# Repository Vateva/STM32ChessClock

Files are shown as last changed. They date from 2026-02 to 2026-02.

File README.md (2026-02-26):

# STM32ChessClock
Two-player chess clock built on an STM32F103C8 (Blue Pill) with dual SH1106 OLED displays, rotary encoders, and 6 time control modes.

Each player has their own display, rotary encoder, and dedicated buttons. The menu system allows fully independent configuration of starting time, time control mode, and bonus time per player -- making it easy to play odds games (e.g. 10 min vs 5 min, or different time control modes for each player).

## Table of Contents
- [Hardware Components](#hardware-components)
- [Assembly](#assembly)
- [Pinout Configuration](#pinout-configuration)
- [Key Features](#key-features)
  - [Game State Machine](#game-state-machine)
  - [6 Time Control Modes](#6-time-control-modes)
  - [Independent Player Menus](#independent-player-menus)
  - [Time Editor](#time-editor)
  - [Input System](#input-system)
  - [Buzzer](#buzzer)
  - [Boot Animation](#boot-animation)
  - [Display](#display)
- [Technical Specifications](#technical-specifications)
  - [Software Architecture](#software-architecture)
  - [Coordinator Pattern](#coordinator-pattern)
- [Build Environment](#build-environment)
- [Configuration](#configuration)
- [Usage](#usage)
- [License](#license)

## Hardware Components
- STM32F103C8 (Blue Pill) running at 8 MHz HSI
- 2x 1.3" OLED + EC11 rotary encoder modules (SH1106 128x64 I2C display, rotary encoder, and 2 tactile buttons per module)
- 2x Tactile buttons (tap per player)
- 1S lithium battery voltage meter module
- Piezo buzzer (8500 Hz)
  
chessclock components

## Assembly

### Prototyping

chessclcok breadboard

### Solder the components together

chesscolockl soldering

### Design and print the casing
<!-- TODO: Add casing photo -->

The `chessclock-CAD/` folder includes all the STL files needed to print the casing and a gift box, as well as the Blender source files if you want to modify the designs.

### Finished product

finished chessclokc

https://github.com/user-attachments/assets/36cff737-d65f-408a-ad59-bc486b68077b

https://github.com/user-attachments/assets/38348769-685e-4487-b6a5-1dc7a97dfc77

## Pinout Configuration

### Player 1
```cpp
// Display (I2C1)
SCL = PB6
SDA = PB7

// Rotary Encoder
CH_A = PA0
CH_B = PA1

// Buttons
Encoder Push = PA2
Menu         = PA3
Back         = PA4
Tap          = PA15
```

### Player 2
```cpp
// Display (I2C2)
SCL = PB10
SDA = PB11

// Rotary Encoder
CH_A = PB12
CH_B = PB13

// Buttons
Encoder Push = PB14
Menu         = PB15
Back         = PA8
Tap          = PA9
```

### Buzzer
```cpp
Buzzer = PA6  // PWM via TIM3
```

## Key Features

### Game State Machine

The game operates in 4 phases:

```mermaid
stateDiagram-v2
    direction LR

    [*] --> Armed

    Armed --> ArmedMenu    : hold menu (2s)
    ArmedMenu --> Armed    : Ready

    Armed --> Running      : tap

    Running --> Running    : active player taps\n(switch turns)
    Running --> PausedMenu : hold menu (2s)
    Running --> Finished   : clock hits 0

    PausedMenu --> Paused  : Ready
    PausedMenu --> Armed   : Reset
    Paused --> PausedMenu  : hold menu (2s)
    Paused --> Running     : tap (resume)

    Finished --> Armed     : any tap
    Finished --> ArmedMenu : hold menu (2s)
```

The menu can be entered from both **Armed** and **Running** by holding the menu button for 2 seconds. From Armed, it offers starting time and mode configuration. From Running, the game pauses and the menu additionally offers current time editing and reset.

- **Armed:** both players ready, waiting for first tap to start
- **Running:** active player's clock counting down, tap to switch turns
- **Paused:** clocks frozen, access menu to edit times or reset
- **Finished:** game over, loser's display blinks, buzzer beeps (if enabled)

### 6 Time Control Modes

| Mode | Behavior | Default Bonus |
|---|---|---|
| **None** | Pure countdown | N/A |
| **Increment (Fischer)** | Add time per move, can accumulate | 3s |
| **Delay (Bronstein)** | Buffer before countdown starts | 2s |
| **Partial** | Add time per move, capped at starting time | 5s |
| **Limited** | Must move within X seconds or lose instantly | 30s |
| **Byo-yomi** | Extra period after main time expires | 30s |

### Independent Player Menus

Each player has their own menu accessible by holding their menu button for 2 seconds. All settings are fully independent per player -- Player 1 can play with 10 minutes + Fischer increment while Player 2 plays with 5 minutes + no bonus, for example.

**Armed Menu:**
1. Starting Time
2. Time Control (mode + bonus)
3. Buzzer (on/off)
4. Ready!

**Paused Menu:**
1. Current Time (live editing)
2. Time Control (mode + bonus)
3. Buzzer (on/off)
4. Reset (with confirmation)
5. Ready!

### Time Editor
- Large HH:MM:SS display with blinking field selection
- Rotate encoder to adjust values, push encoder to move between fields
- Hold encoder for 1 second to save
- Values loop within limits (0-23 hours, 0-59 minutes/seconds)

### Input System
- **Rotary Encoders:** quadrature decoding via EXTI interrupts, 20 detents per rotation
- **Button Debouncing:** 50ms settling time
- **Menu Hold Detection:** 2-second hold to enter menu
- **Stale Press Clearing:** button events flushed on state transitions

### Buzzer
- 3 beeps on game finish (500ms on, 250ms off pattern)
- Toggleable from either player's menu
- 8500 Hz PWM at 90% duty cycle (piezo resonant frequency)

### Boot Animation
4-frame splash screen displayed on both OLEDs at startup.

<!-- TODO: Add demo video -->

### Display
- Smart partial redraws to minimize flicker
- Display cache prevents redundant I2C writes
- Header shows mode name and bonus time
- Large clock digits (16x24 font)

## Technical Specifications

| Component | Specification |
|---|---|
| **MCU** | STM32F103C8 (ARM Cortex-M3) @ 8 MHz HSI |
| **Displays** | 2x SH1106 OLED 128x64, I2C @ 400 kHz |
| **Encoders** | Quadrature, 20 detents, 4 pulses/detent |
| **Clock Precision** | 100ms tick via TIM2 interrupt |
| **Time Range** | 1 second to 24 hours |
| **Bonus Range** | 0 to 60 seconds |
| **Buzzer** | Piezo, 8500 Hz PWM via TIM3 |
| **Upload** | Serial (UART bootloader) |

### Software Architecture

| Module | Purpose |
|---|---|
| `main.c` | Coordinator between game and menu modules |
| `game.c` | Game state machine, clock logic, input handling |
| `menu.c` | Menu navigation, time editing, mode selection |
| `display.c` | SH1106 OLED driver (I2C) |
| `hardware.c` | GPIO, I2C, timer initialization |
| `button.c` | Debouncing and edge detection |
| `encoder.c` | Quadrature decoding via interrupts |
| `config.h` | All pin definitions, constants, and types |
| `fonts.h` | Font data (5x7, 8x16, 16x24) |
| `splash.h` | Boot animation frame data |

### Coordinator Pattern
The game and menu modules are fully decoupled. `main.c` bridges them:
- Detects when a player enters the menu (game sets `in_menu` flag)
- Calls `menu_open()` with pointers to editable config/time values
- Relays menu actions (`READY`, `RESET`) back to the game module
- Syncs mode changes to update bonus times

## Build Environment

### PlatformIO Configuration
```ini
[env:genericSTM32F103C8]
platform = ststm32
board = genericSTM32F103C8
framework = stm32cube

build_flags =
    -DUSE_HAL_DRIVER
    -DSTM32F103xB

upload_protocol = serial
```

Upload via UART bootloader with default PlatformIO settings.

## Configuration

All parameters can be adjusted in `config.h`:

### Timing
```cpp
CLOCK_TICK_INTERVAL_MS        = 100      // decisecond precision
MENU_BUTTON_HOLD_TIME_MS      = 2000     // hold to enter menu
BUTTON_DEBOUNCE_TIME_MS       = 50       // button settling time
ENCODER_LONG_PRESS_TIME_MS    = 1000     // hold encoder to save
```

### Defaults
```cpp
DEFAULT_STARTING_TIME_MS      = 300000   // 5 minutes
DEFAULT_BONUS_INCREMENT_MS    = 3000     // 3 seconds
DEFAULT_BONUS_DELAY_MS        = 2000     // 2 seconds
DEFAULT_BONUS_PARTIAL_MS      = 5000     // 5 seconds
DEFAULT_BONUS_LIMITED_MS      = 30000    // 30 seconds
DEFAULT_BONUS_BYOYOMI_MS      = 30000    // 30 seconds
```

### Buzzer
```cpp
BUZZER_PWM_FREQUENCY_HZ       = 8500     // piezo resonant frequency
BUZZER_PWM_DUTY_CYCLE_PERCENT  = 90       // duty cycle
BUZZER_BEEP_DURATION_MS        = 500      // beep length
BUZZER_PAUSE_DURATION_MS       = 250      // pause between beeps
```

## Usage

### First Boot
1. Both displays show the splash animation
2. Game starts in Armed phase with default settings (5 min, no time control)
3. Both displays show "Ready!" with the clock at 05:00

### Starting a Game
1. Player 1 or Player 2 taps their button to start
2. The **other** player's clock begins counting down
3. Tap to switch turns -- the active player's clock stops and the opponent's starts

### During a Game
- **Tap:** switch turns (applies time control bonus to current player)
- **Hold Menu (2s):** pause the game and enter menu
- **Time expires:** game ends, loser's display blinks, buzzer beeps 3x

### Menu Navigation
- **Encoder rotation:** move cursor up/down or adjust values
- **Encoder push:** select item or advance to next field
- **Encoder long press (1s):** save in time editor
- **Back button:** return to previous screen

https://github.com/user-attachments/assets/ae7eb4f5-54fc-41e0-8311-3a073d8e431d

## License
MIT License - feel free to use, modify, and distribute.

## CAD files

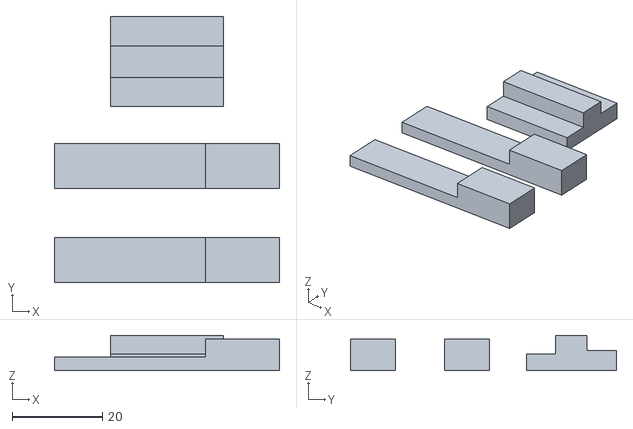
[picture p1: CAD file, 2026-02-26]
chessclock-CAD/stl/chessclock stl/chess clock display holder.stl
50.0 x 59.0 x 7.80

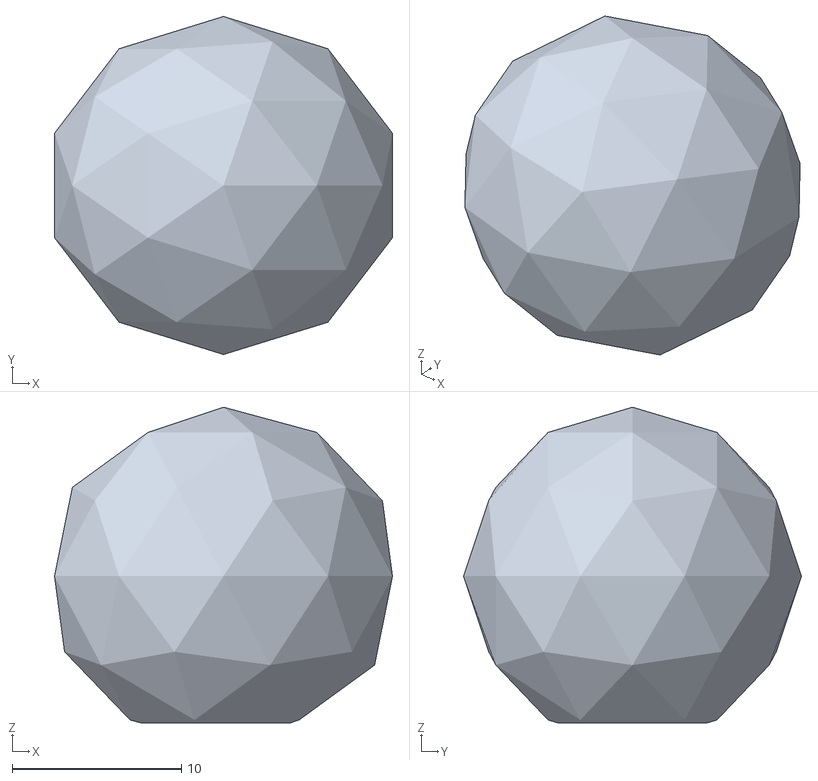
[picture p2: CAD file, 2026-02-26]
chessclock-CAD/stl/gift box stl/chessclock gift box cover handle.stl
20.0 x 20.0 x 18.7

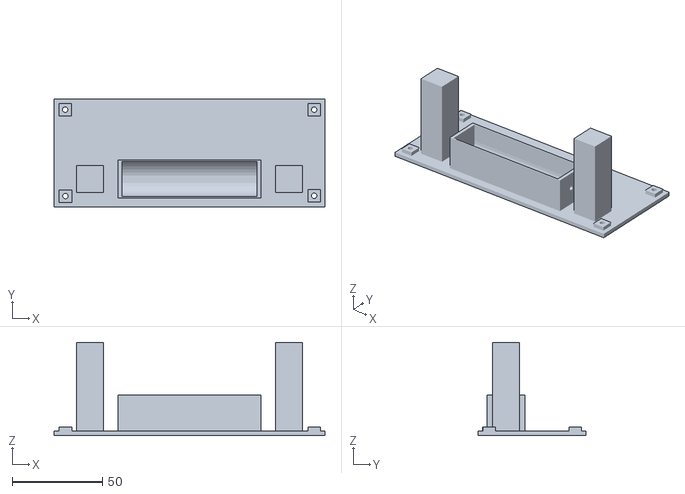
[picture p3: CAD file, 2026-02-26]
chessclock-CAD/stl/chessclock stl/chessclock BASE.stl
150.0 x 60.0 x 51.5

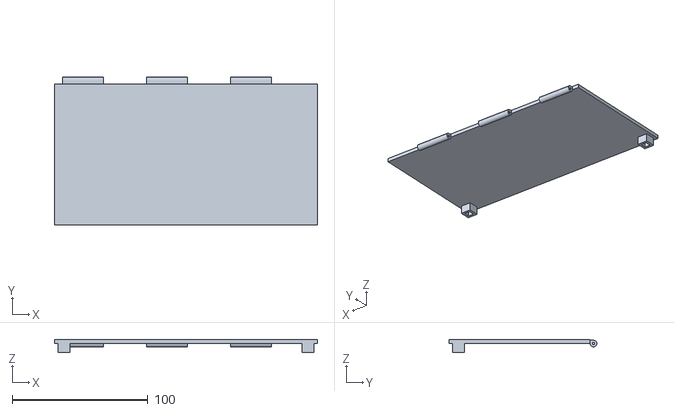
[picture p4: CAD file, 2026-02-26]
chessclock-CAD/stl/gift box stl/chessclock gift box cover.stl
194.0 x 109.0 x 9.65

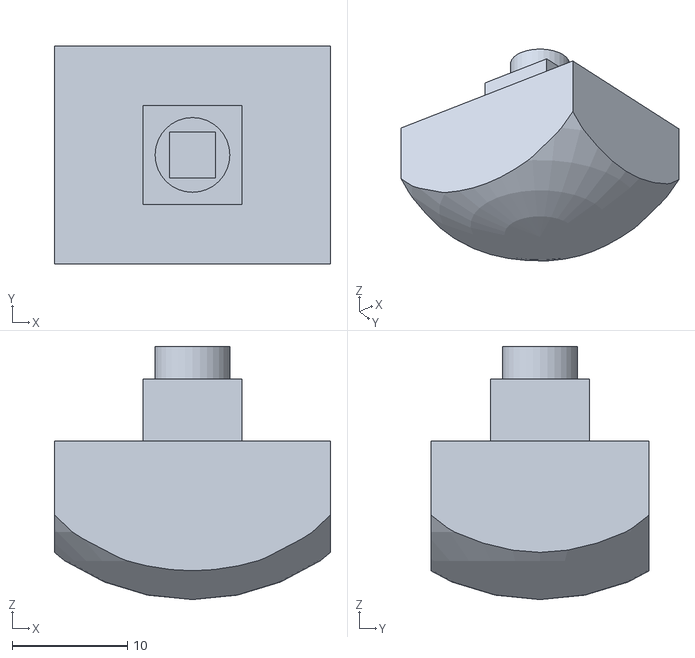
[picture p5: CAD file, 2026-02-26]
chessclock-CAD/stl/chessclock stl/chessclock tap button.stl
24.0 x 19.0 x 22.0

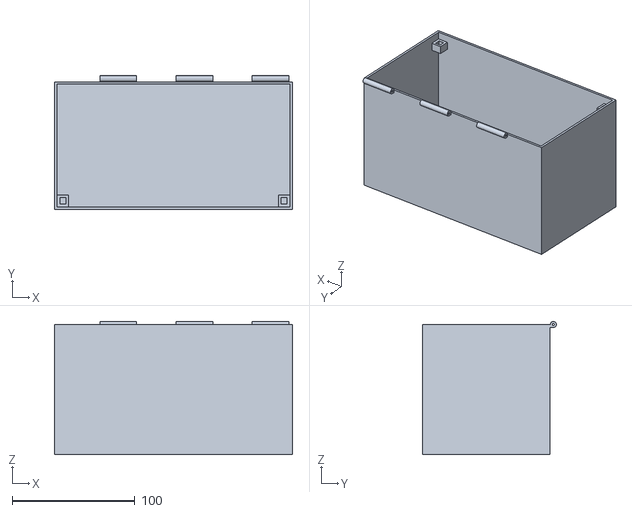
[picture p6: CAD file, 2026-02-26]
chessclock-CAD/stl/gift box stl/chessclock gift box.stl
194.0 x 109.0 x 108.6

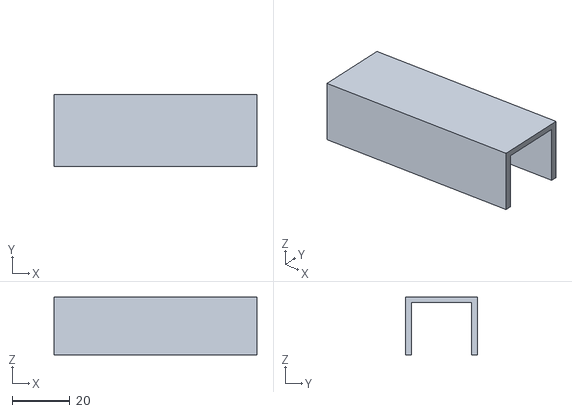
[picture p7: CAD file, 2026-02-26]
chessclock-CAD/stl/chessclock stl/chessclock-battery-holder-clip.stl
70.0 x 25.0 x 20.0

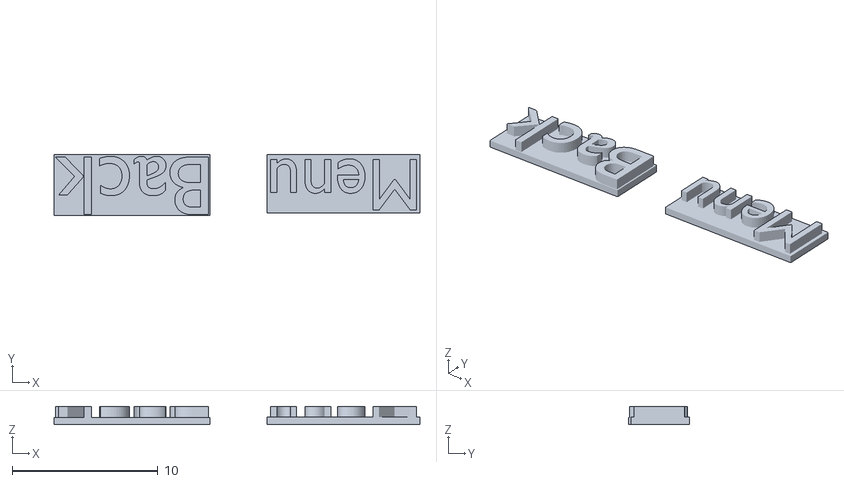
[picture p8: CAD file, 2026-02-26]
chessclock-CAD/stl/chessclock stl/chessclock-button-text.stl
25.1 x 4.20 x 1.24

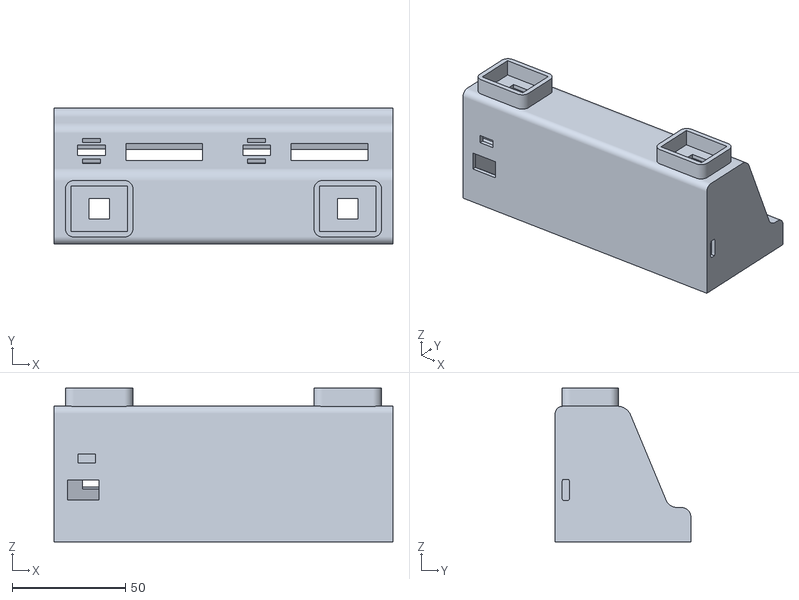
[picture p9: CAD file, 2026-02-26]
chessclock-CAD/stl/chessclock stl/chessclock BODY.stl
150.0 x 60.0 x 68.0

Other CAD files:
chessclock-CAD/chess clock display holder.blend
chessclock-CAD/chessclock gift box.blend
chessclock-CAD/chessclock.blend

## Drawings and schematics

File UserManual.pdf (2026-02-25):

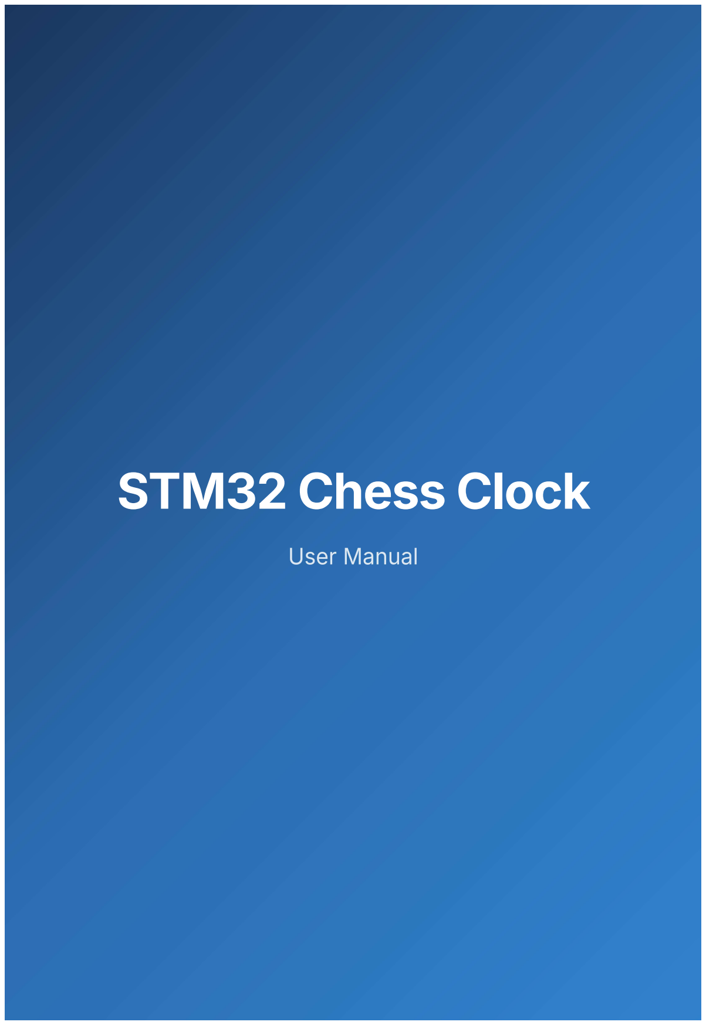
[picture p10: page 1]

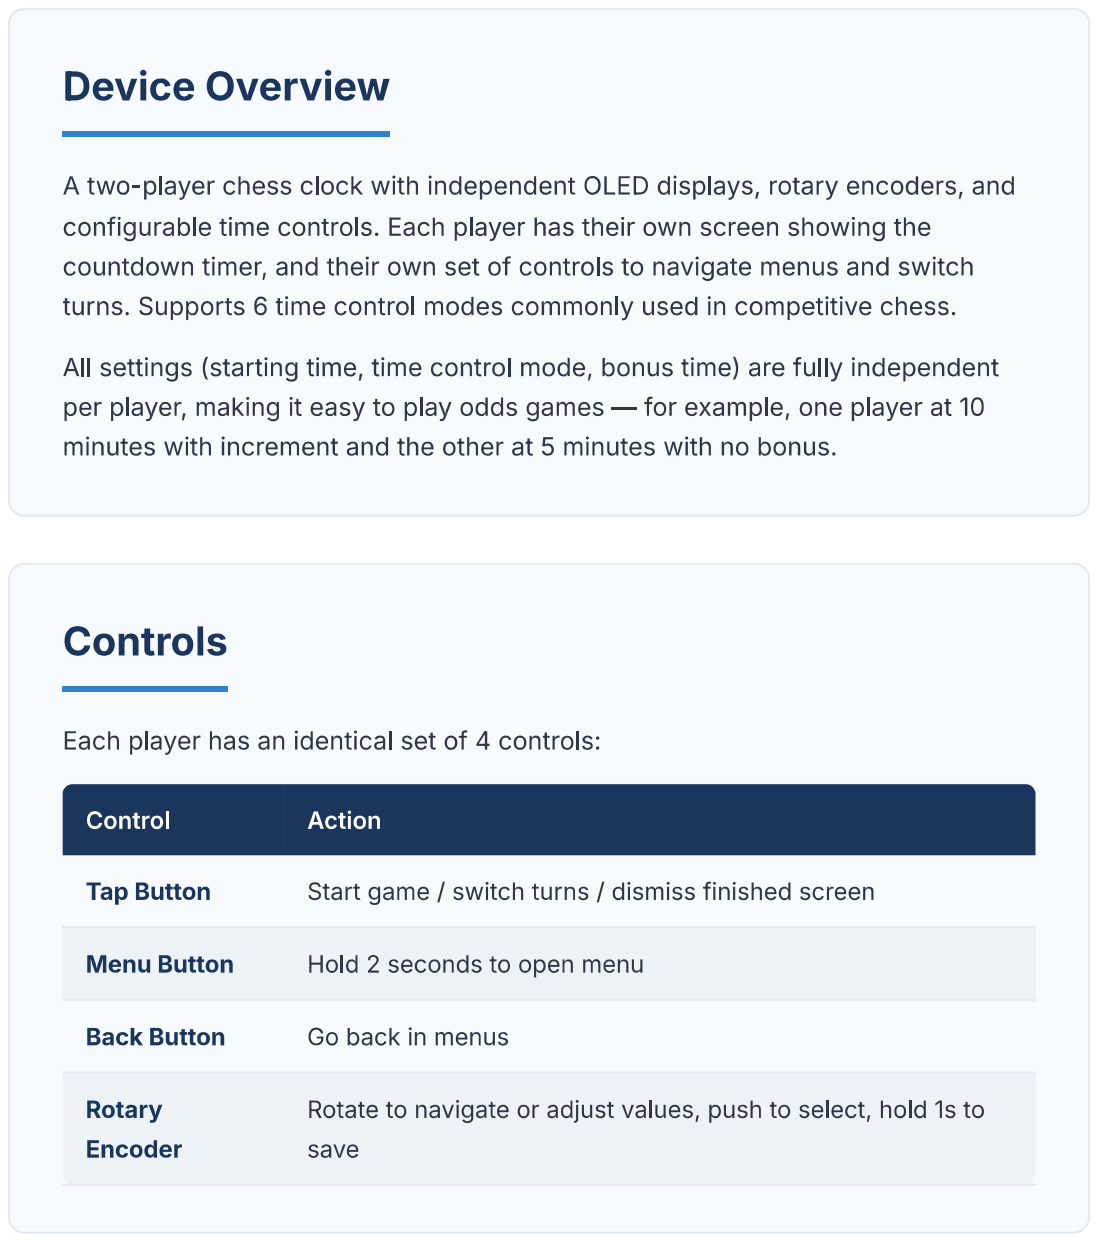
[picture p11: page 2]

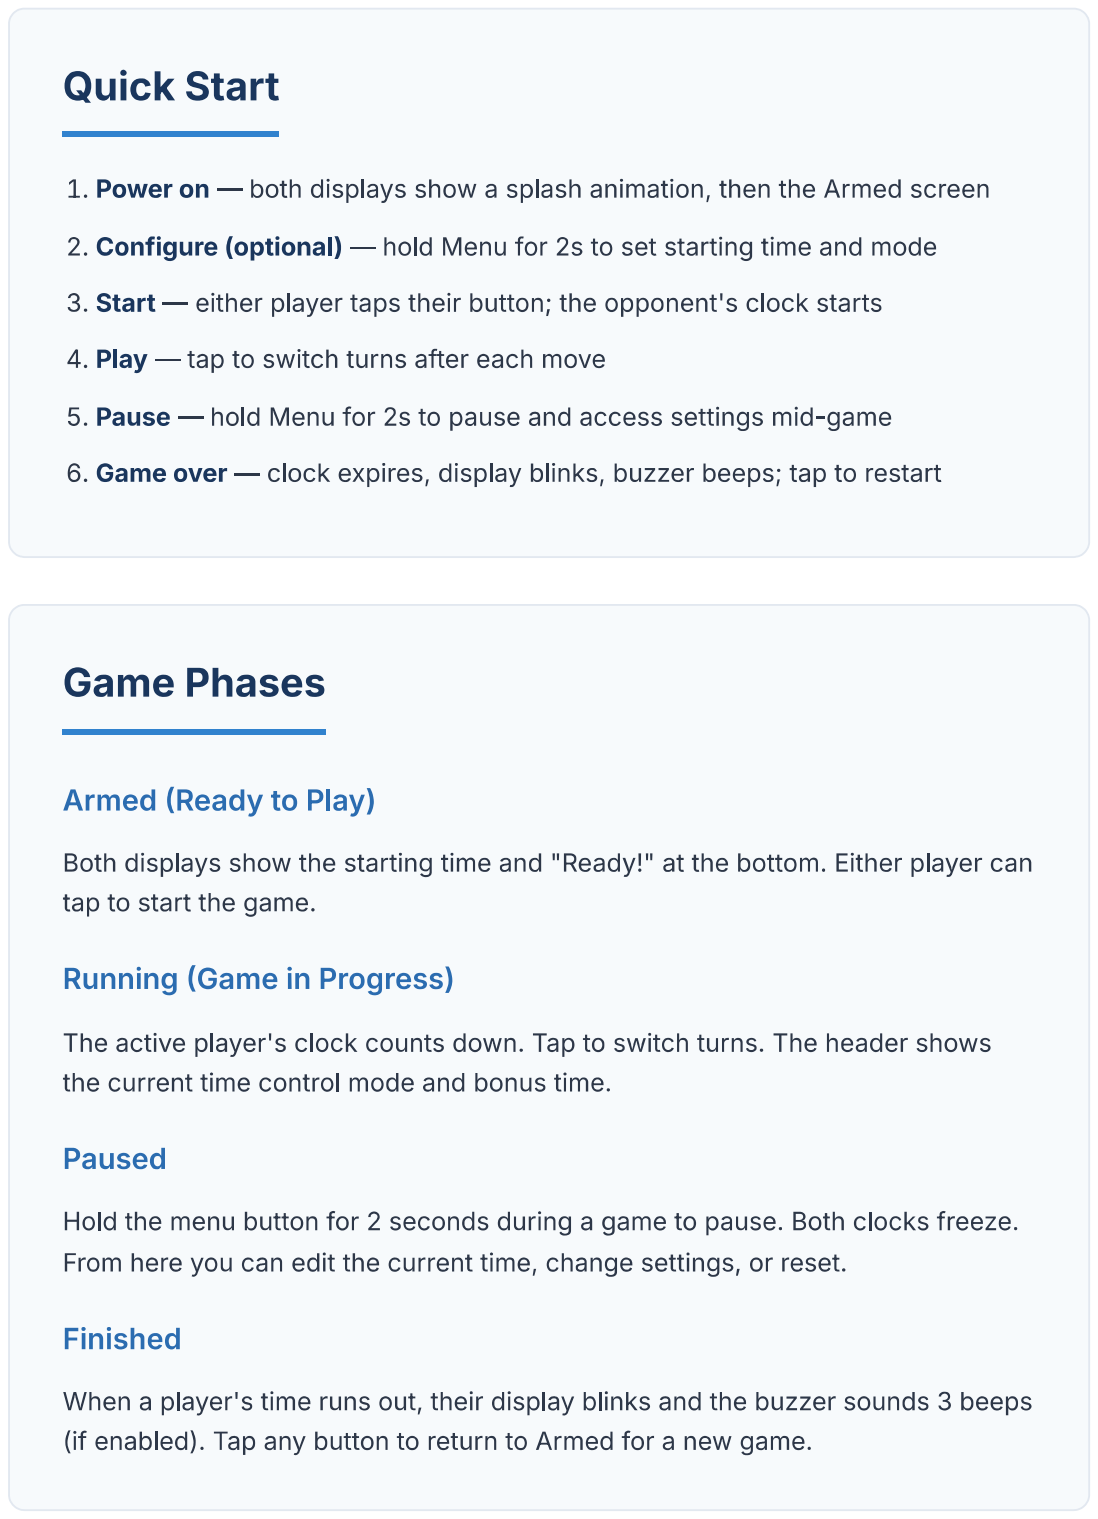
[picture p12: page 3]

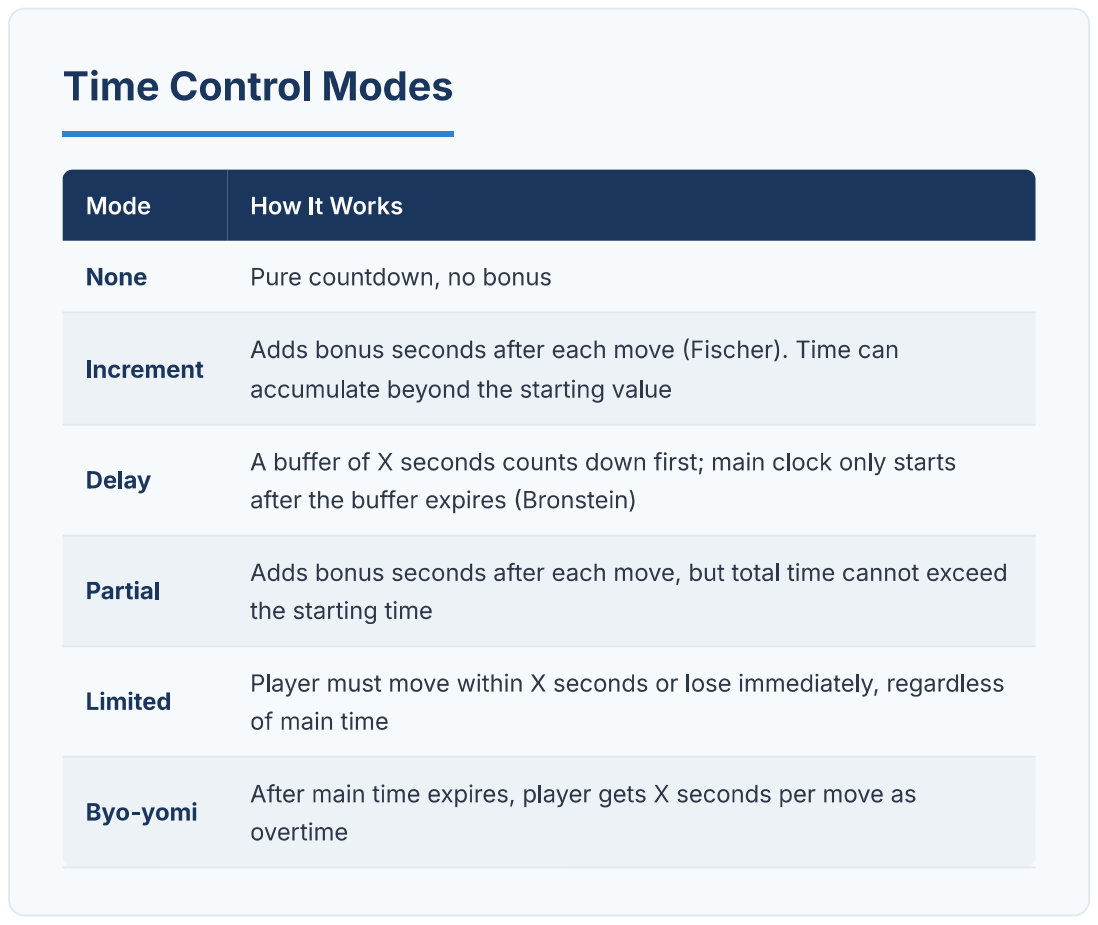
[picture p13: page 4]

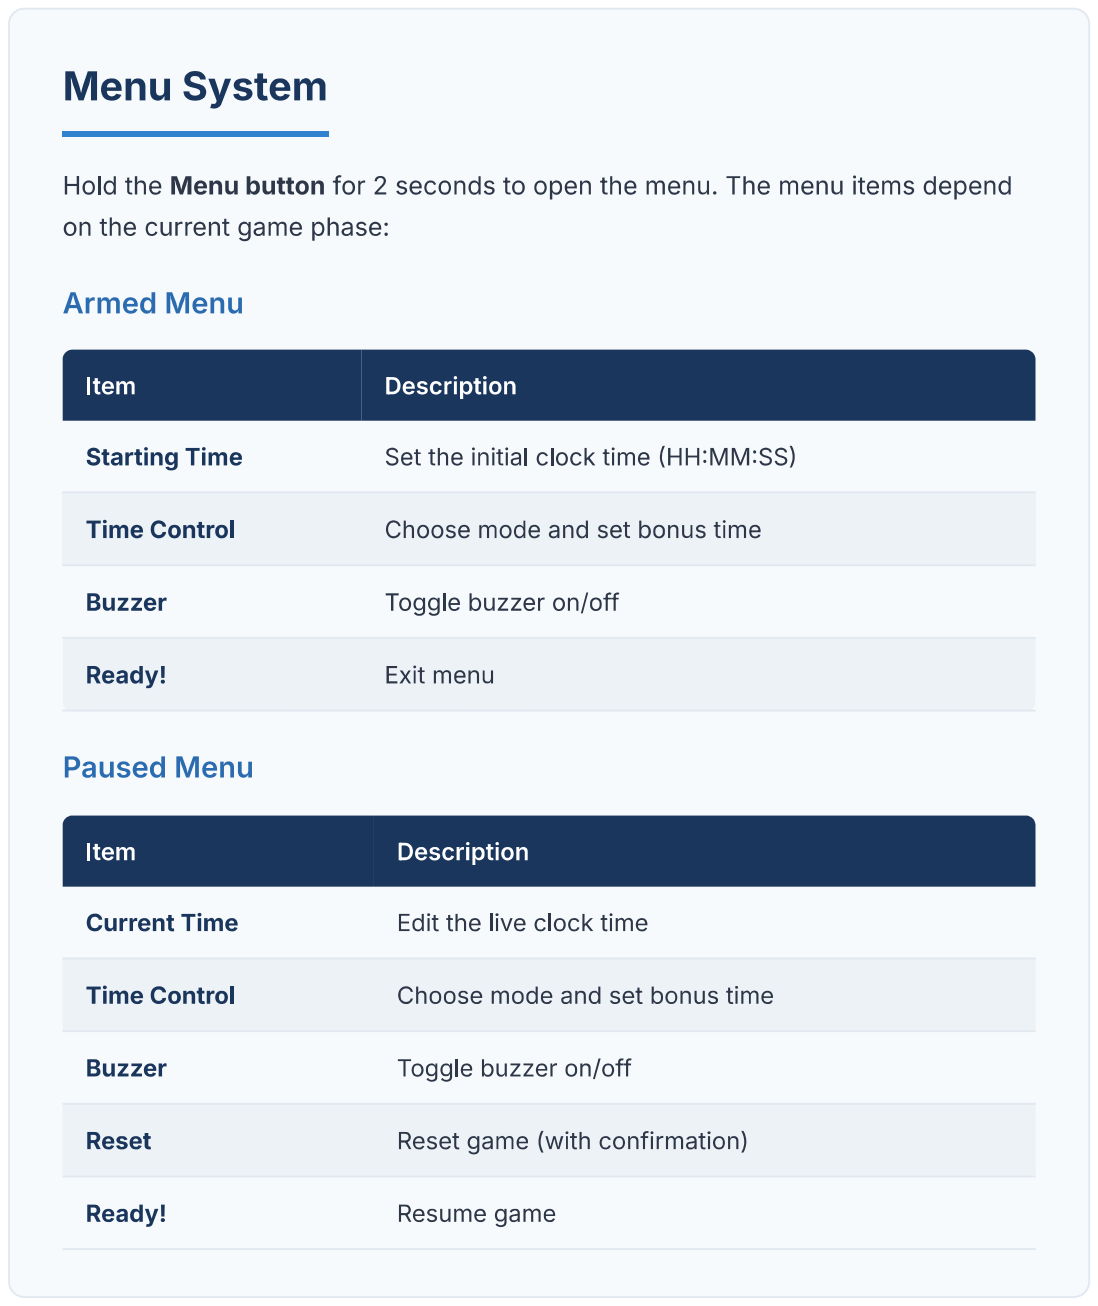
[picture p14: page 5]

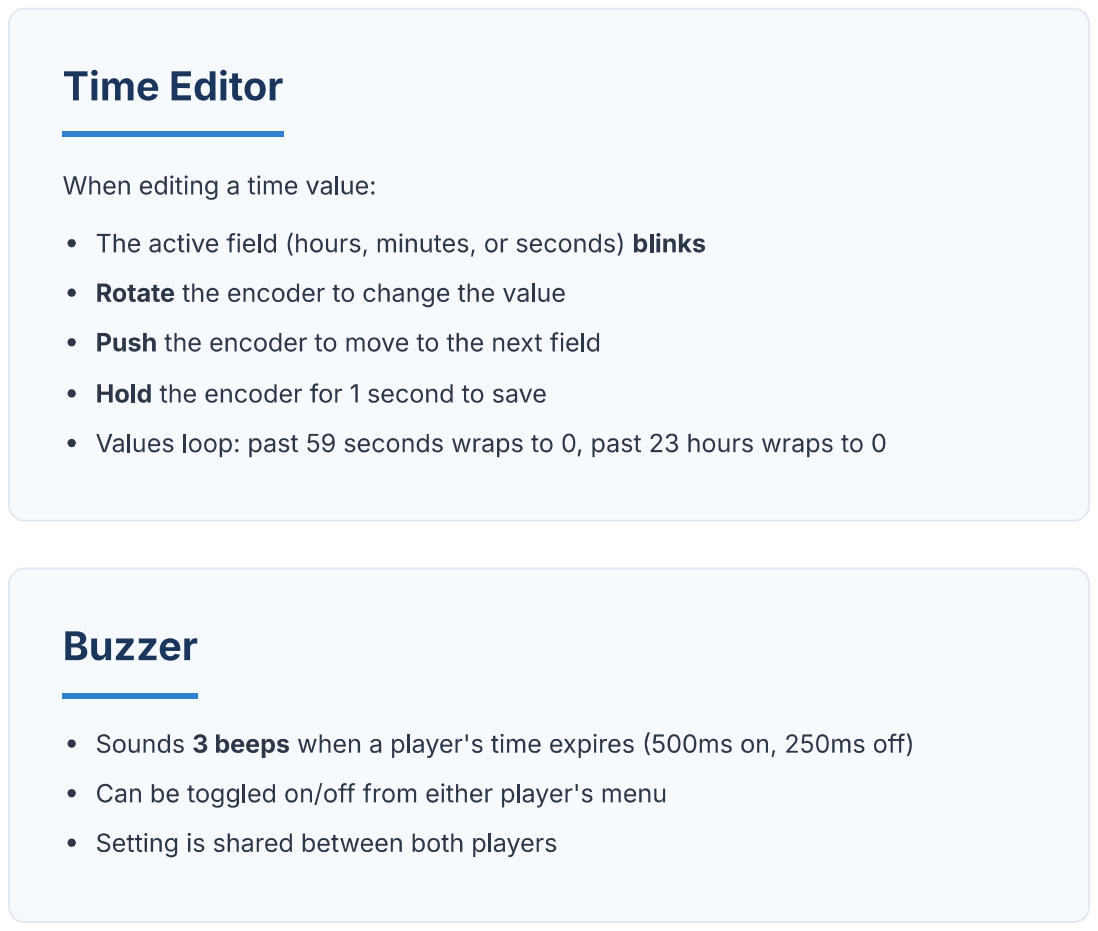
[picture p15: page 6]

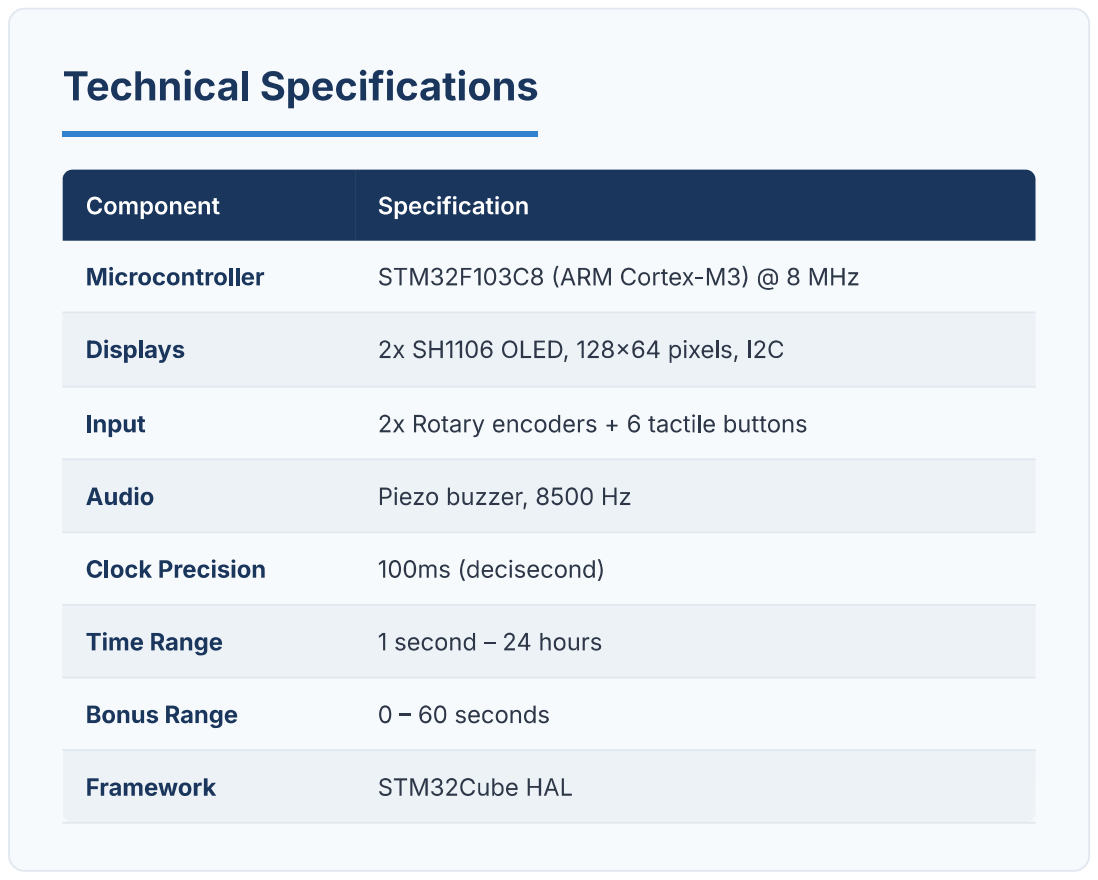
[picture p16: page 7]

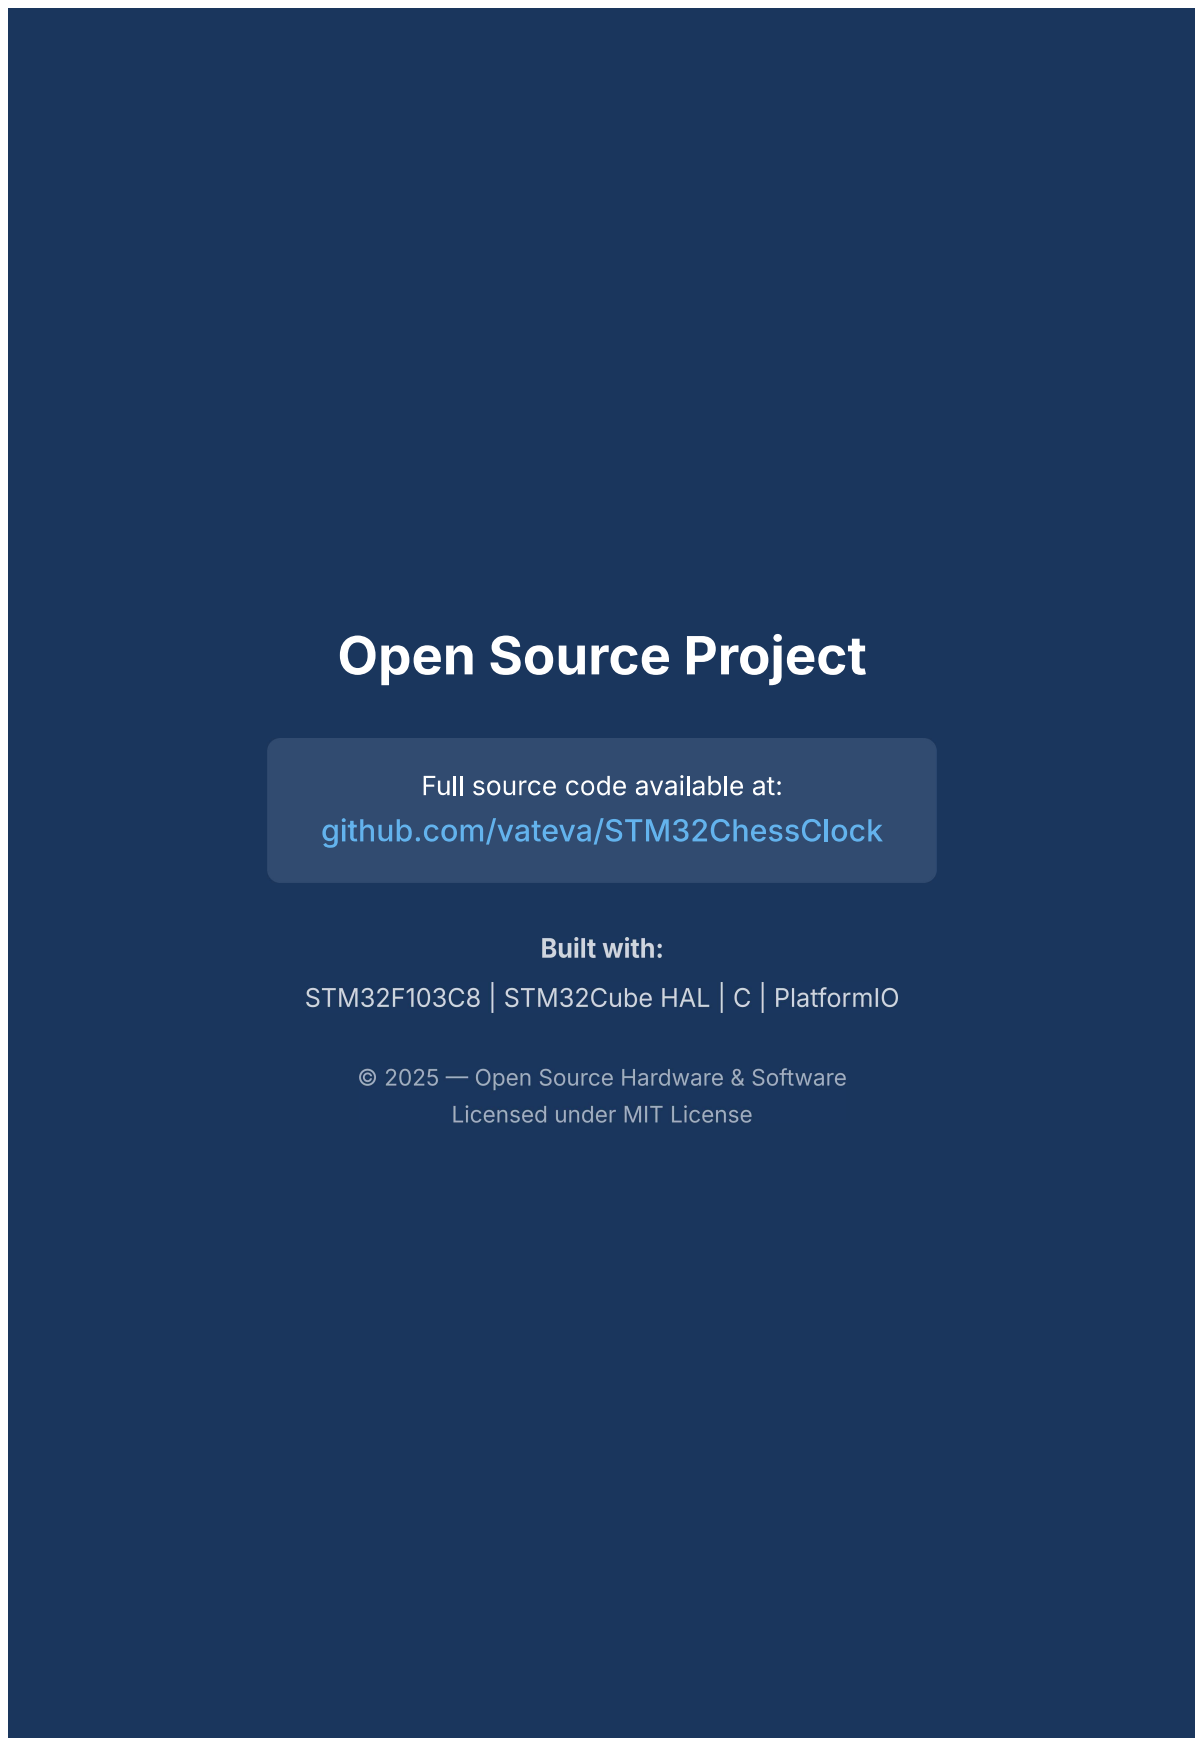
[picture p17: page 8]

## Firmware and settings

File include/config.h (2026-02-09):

/*
 * configuration file for the chess clock
 * contains all pin definitions, hardware addresses, and configurable parameters
 */

#ifndef CONFIG_H
#define CONFIG_H

#include "stm32f1xx_hal.h"

// <---- boolean definitions ---->

#define FALSE 0
#define TRUE  1

// <---- player 1 hardware pin definitions ---->

// player 1 i2c pins for display
#define PLAYER1_I2C_SCL_PIN              GPIO_PIN_6
#define PLAYER1_I2C_SDA_PIN              GPIO_PIN_7
#define PLAYER1_I2C_PORT                 GPIOB
#define PLAYER1_I2C_INSTANCE             I2C1

// player 1 rotary encoder pins
#define PLAYER1_ENCODER_A_PIN            GPIO_PIN_0
#define PLAYER1_ENCODER_B_PIN            GPIO_PIN_1
#define PLAYER1_ENCODER_PORT             GPIOA

// player 1 button pins (all on same port)
#define PLAYER1_ENCODER_PUSH_PIN         GPIO_PIN_2
#define PLAYER1_MENU_BUTTON_PIN          GPIO_PIN_3
#define PLAYER1_BACK_BUTTON_PIN          GPIO_PIN_4
#define PLAYER1_TAP_BUTTON_PIN           GPIO_PIN_15
#define PLAYER1_BUTTON_PORT              GPIOA

// <---- player 2 hardware pin definitions ---->

// player 2 i2c pins for display
#define PLAYER2_I2C_SCL_PIN              GPIO_PIN_10
#define PLAYER2_I2C_SDA_PIN              GPIO_PIN_11
#define PLAYER2_I2C_PORT                 GPIOB
#define PLAYER2_I2C_INSTANCE             I2C2

// player 2 rotary encoder pins
#define PLAYER2_ENCODER_A_PIN            GPIO_PIN_12
#define PLAYER2_ENCODER_B_PIN            GPIO_PIN_13
#define PLAYER2_ENCODER_PORT             GPIOB

// player 2 button pins (split across two ports)
#define PLAYER2_ENCODER_PUSH_PIN         GPIO_PIN_14
#define PLAYER2_MENU_BUTTON_PIN          GPIO_PIN_15
#define PLAYER2_BUTTON_PORT_B            GPIOB
#define PLAYER2_BACK_BUTTON_PIN          GPIO_PIN_8
#define PLAYER2_TAP_BUTTON_PIN           GPIO_PIN_9
#define PLAYER2_BUTTON_PORT_A            GPIOA

// <---- buzzer pin definitions ---->

#define BUZZER_PIN                       GPIO_PIN_6
#define BUZZER_PORT                      GPIOA
#define BUZZER_TIMER_INSTANCE            TIM3
#define BUZZER_TIMER_CHANNEL             TIM_CHANNEL_1

// <---- display configuration (sh1106 oled) ---->

#define DISPLAY_I2C_ADDRESS              (0x3C << 1)  // shift for hal i2c format
#define DISPLAY_WIDTH                    128
#define DISPLAY_HEIGHT                   64
#define DISPLAY_PAGES                    8            // 64 pixels / 8 = 8 pages

// <---- timing configuration ---->

// system clock configuration
#define SYSTEM_CLOCK_FREQUENCY_MHZ       8           // using hsi oscillator

// timer configuration for buzzer pwm
#define BUZZER_PWM_FREQUENCY_HZ          8500         // resonant frequency of piezo
#define BUZZER_PWM_DUTY_CYCLE_PERCENT    90           // percentage (0-100)

// clock tick precision
#define CLOCK_TICK_INTERVAL_MS           100          // update every 100ms (decisecond)

// <---- chess clock defaults and limits ---->

// default starting time (in milliseconds)
#define DEFAULT_STARTING_TIME_MS              300000    // 5 minutes

// default bonus time per mode (in milliseconds)
#define DEFAULT_BONUS_NONE_MS                 0         // not used
#define DEFAULT_BONUS_INCREMENT_MS            3000      // 3 seconds
#define DEFAULT_BONUS_DELAY_MS                2000      // 2 seconds
#define DEFAULT_BONUS_PARTIAL_MS              5000      // 5 seconds
#define DEFAULT_BONUS_LIMITED_MS              30000     // 30 seconds
#define DEFAULT_BONUS_BYOYOMI_MS              30000     // 30 seconds

// time limits (in milliseconds)
#define MIN_STARTING_TIME_MS             1000         // 1 second minimum
#define MAX_STARTING_TIME_MS             86400000     // 24 hours maximum
#define MIN_BONUS_TIME_MS                0            // no bonus time minimum
#define MAX_BONUS_TIME_MS                60000        // 60 seconds maximum

// time editor configuration
#define TIME_EDITOR_HOURS_MAX            23           // 0-23 hours
#define TIME_EDITOR_MINUTES_MAX          59           // 0-59 minutes
#define TIME_EDITOR_SECONDS_MAX          59           // 0-59 seconds
#define BONUS_TIME_EDITOR_SECONDS_MAX    59           // 0-59 seconds for increment/delay

// <---- encoder configuration ---->

#define ENCODER_CLICKS_PER_ROTATION      20           // physical detents per full rotation
#define ENCODER_PULSES_PER_CLICK         4            // quadrature pulses per click
#define ENCODER_DEBOUNCE_TIME_MS         5            // minimum ms between state changes

// <---- button configuration ---->

#define BUTTON_ACTIVE_STATE              GPIO_PIN_RESET  // buttons are active-low
#define BUTTON_DEBOUNCE_TIME_MS          50              // debounce delay
#define MENU_BUTTON_HOLD_TIME_MS         2000            // hold 2 seconds to enter menu

// <---- time control modes ---->

typedef enum {
    TIME_CONTROL_NONE,      // no bonus time
    TIME_CONTROL_INCREMENT, // fischer increment (add X, can accumulate)
    TIME_CONTROL_DELAY,     // bronstein delay (X second buffer before countdown)
    TIME_CONTROL_PARTIAL,   // partial increment (add X, capped at turn start time)
    TIME_CONTROL_LIMITED,   // limited time (must move within X seconds or lose)
    TIME_CONTROL_BYOYOMI    // byo-yomi (X seconds per move after main time expires)
} time_control_mode_t;

#define DEFAULT_TIME_CONTROL_MODE        TIME_CONTROL_NONE
#define TIME_CONTROL_MODE_COUNT          6  // total number of modes

// <---- player configuration (shared between game and menu modules) ---->

// per-player settings configured via menu, used as template for new games
typedef struct {
    uint32_t starting_time_ms;              // configured starting time in milliseconds
    time_control_mode_t time_control_mode;  // selected time control mode
    uint32_t bonus_time_ms[TIME_CONTROL_MODE_COUNT];  // bonus time per mode in milliseconds
} player_config_t;

// <---- menu configuration ---->

#define MENU_SAVE_FEEDBACK_DURATION_MS   500  // "Saved!" display duration
#define MENU_BLINK_INTERVAL_MS           300  // blink rate for editing fields
#define ENCODER_LONG_PRESS_TIME_MS       1000 // long press encoder to save in time editor

// <---- interrupt priorities ---->

#define ENCODER_INTERRUPT_PRIORITY       5            // encoder gpio exti priority
#define TIMER_INTERRUPT_PRIORITY         3            // clock tick timer priority

#endif // CONFIG_H

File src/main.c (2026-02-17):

/*
 * chess clock main program
 * wires together game and menu modules
 * acts as coordinator — neither module knows about the other
 */

#include "stm32f1xx_hal.h"
#include "config.h"
#include "hardware.h"
#include "display.h"
#include "button.h"
#include "encoder.h"
#include "game.h"
#include "menu.h"

// <---- internal helper: open menu for a player ---->

// game module sets in_menu flag but doesn't open the menu module
// main.c detects the flag transition and calls menu_open
static uint8_t prev_in_menu[PLAYER_COUNT] = {FALSE, FALSE};
// tracks mode at menu open to detect mode changes on menu exit
static time_control_mode_t mode_at_menu_open[PLAYER_COUNT];

// reads game state and passes the right pointers to the menu module
static void open_menu_for_player(player_id_t player) {
    player_state_t* ps = game_get_player_state(player);
    game_phase_t phase = game_get_phase();

    // determine whether we're editing a paused game or configuring a new one
    // note: RUNNING transitions to PAUSED before menu opens (handled by game module)
    // FINISHED transitions to ARMED before menu opens (handled by game module)
    // so by this point phase is either ARMED or PAUSED
    uint8_t is_paused = (phase == GAME_PHASE_PAUSED) ? TRUE : FALSE;

    if (is_paused) {
        // determine which bonus pointer to pass based on mode type
        uint32_t* bonus_ptr;
        time_control_mode_t mode = ps->config.time_control_mode;

        if (mode == TIME_CONTROL_DELAY ||
            mode == TIME_CONTROL_LIMITED ||
            mode == TIME_CONTROL_BYOYOMI) {
            // countdown modes: edit the live bonus timer
            bonus_ptr = &ps->current_bonus_ms;
        } else if (mode == TIME_CONTROL_INCREMENT ||
                   mode == TIME_CONTROL_PARTIAL) {
            // increment modes: edit the configured increment amount
            bonus_ptr = &ps->config.bonus_time_ms[mode];
        } else {
            // none: no bonus to edit
            bonus_ptr = NULL;
        }

        // remember mode at menu open to detect changes on exit
        mode_at_menu_open[player] = ps->config.time_control_mode;

        menu_open((uint8_t)player,
                  &ps->config,
                  &ps->current_time_ms,
                  bonus_ptr,
                  TRUE,
                  &game_get_state()->buzzer_enabled);
    } else {
        // configuring new game: no live values to edit
        menu_open((uint8_t)player,
                  &ps->config,
                  NULL,
                  NULL,
                  FALSE,
                  &game_get_state()->buzzer_enabled);
    }
}

// <---- internal helper: handle menu results for a player ---->

// checks menu actions and relays them to game module
static void process_menu_result(player_id_t player) {
    if (!menu_is_open((uint8_t)player)) {
        return;
    }

    menu_action_t action = menu_update((uint8_t)player);

    switch (action) {
        case MENU_ACTION_READY: {
            player_state_t* ps = game_get_player_state(player);
            time_control_mode_t active_mode = ps->config.time_control_mode;

            // only sync live bonus if player changed the mode during this menu session
            // if mode is unchanged, the time editor's edit to current_bonus_ms is preserved
            if (active_mode != mode_at_menu_open[player]) {
                if (active_mode == TIME_CONTROL_DELAY ||
                    active_mode == TIME_CONTROL_LIMITED ||
                    active_mode == TIME_CONTROL_BYOYOMI) {
                    ps->current_bonus_ms = ps->config.bonus_time_ms[active_mode];
                }
            }

            game_player_ready(player);
            break;
        }

        case MENU_ACTION_RESET:
            // player confirmed reset — tell game module
            game_request_reset();
            break;

        case MENU_ACTION_NONE:
            // menu still active, nothing to relay
            break;

        default:
            break;
    }
}

// <---- internal helper: detect menu entry and call menu_open ---->

static void check_menu_open(void) {
    for (uint8_t i = 0; i < PLAYER_COUNT; i++) {
        player_state_t* ps = game_get_player_state((player_id_t)i);

        // detect transition: was not in menu, now is in menu
        if (ps->in_menu && !prev_in_menu[i]) {
            open_menu_for_player((player_id_t)i);
        }

        prev_in_menu[i] = ps->in_menu;
    }
}

// <---- interrupt handlers ---->

// systick handler: required for hal timing (HAL_GetTick, HAL_Delay)
void SysTick_Handler(void) {
    HAL_IncTick();
}

// tim2 handler: fires every 100ms, decrements active player's clock
void TIM2_IRQHandler(void) {
    HAL_TIM_IRQHandler(hardware_get_tim2());
    game_tick();
}

// <---- main ---->

int main(void) {
    // initialize hal
    HAL_Init();

    // initialize all hardware subsystems
    hardware_init();

    // initialize input modules
    button_init();
    encoder_init();

    // initialize displays
    I2C_HandleTypeDef* i2c1 = hardware_get_i2c1();
    I2C_HandleTypeDef* i2c2 = hardware_get_i2c2();
    HAL_Delay(100);
    display_init(i2c1);
    display_init(i2c2);

    // show boot splash animation
    display_show_splash(i2c1, i2c2);

    // clear displays before drawing clock screen
    display_clear(i2c1);
    display_clear(i2c2);

    // initialize game and menu modules
    game_init();
    menu_init();

    // main loop
    while (1) {
        // poll button states
        button_update();

        // detect menu open transitions and wire to menu module
        check_menu_open();

        // update menu for players who are in menu
        // relay any actions back to game module
        process_menu_result(PLAYER_1);
        process_menu_result(PLAYER_2);

        // run game state machine (input handling, transitions, display)
        game_update();

        // small delay to prevent cpu spinning too fast
        HAL_Delay(1);
    }
}

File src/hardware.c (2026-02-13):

/*
 * hardware abstraction layer implementation
 */

#include "hardware.h"

#include "config.h"

// <---- private hardware handles ---->

// i2c handles for displays
static I2C_HandleTypeDef hi2c1;
static I2C_HandleTypeDef hi2c2;

// timer handles
static TIM_HandleTypeDef htim2;  // clock tick timer (100ms interrupts)
static TIM_HandleTypeDef htim3;  // buzzer pwm timer

// <---- main initialization function ---->

void hardware_init(void) {
  // initialize subsystems in correct order
  hardware_init_system_clock();
  hardware_init_gpio();
  hardware_init_i2c();
  hardware_init_timers();
}

// <---- system clock configuration ---->

void hardware_init_system_clock(void) {
  RCC_OscInitTypeDef RCC_OscInitStruct = {0};
  RCC_ClkInitTypeDef RCC_ClkInitStruct = {0};

  // configure hsi oscillator (8mhz internal)
  // use directly without pll for lower power consumption
  RCC_OscInitStruct.OscillatorType = RCC_OSCILLATORTYPE_HSI;
  RCC_OscInitStruct.HSIState = RCC_HSI_ON;
  RCC_OscInitStruct.HSICalibrationValue = RCC_HSICALIBRATION_DEFAULT;
  RCC_OscInitStruct.PLL.PLLState = RCC_PLL_NONE;  // no pll
  HAL_RCC_OscConfig(&RCC_OscInitStruct);

  // configure system clocks
  // sysclk = 8mhz (from hsi)
  // ahb = 8mhz (no division)
  // apb1 = 8mhz (no division)
  // apb2 = 8mhz (no division)
  RCC_ClkInitStruct.ClockType = RCC_CLOCKTYPE_HCLK | RCC_CLOCKTYPE_SYSCLK | RCC_CLOCKTYPE_PCLK1 | RCC_CLOCKTYPE_PCLK2;
  RCC_ClkInitStruct.SYSCLKSource = RCC_SYSCLKSOURCE_HSI;
  RCC_ClkInitStruct.AHBCLKDivider = RCC_SYSCLK_DIV1;  // 8mhz
  RCC_ClkInitStruct.APB1CLKDivider = RCC_HCLK_DIV1;   // 8mhz
  RCC_ClkInitStruct.APB2CLKDivider = RCC_HCLK_DIV1;   // 8mhz
  HAL_RCC_ClockConfig(&RCC_ClkInitStruct, FLASH_LATENCY_0);
}

// <---- gpio initialization ---->

void hardware_init_gpio(void) {
  GPIO_InitTypeDef GPIO_InitStruct = {0};

  // enable gpio and afio clocks (afio needed for exti on stm32f1)
  __HAL_RCC_GPIOA_CLK_ENABLE();
  __HAL_RCC_GPIOB_CLK_ENABLE();
  __HAL_RCC_AFIO_CLK_ENABLE();

  // <---- player 1 gpio configuration ---->

  // player 1 encoder pins (exti on both edges for interrupt-driven quadrature decoding)
  GPIO_InitStruct.Pin = PLAYER1_ENCODER_A_PIN | PLAYER1_ENCODER_B_PIN;
  GPIO_InitStruct.Mode = GPIO_MODE_IT_RISING_FALLING;
  GPIO_InitStruct.Pull = GPIO_PULLUP;
  GPIO_InitStruct.Speed = GPIO_SPEED_FREQ_LOW;
  HAL_GPIO_Init(PLAYER1_ENCODER_PORT, &GPIO_InitStruct);

  // enable exti interrupts for player 1 encoder (pa0 -> exti0, pa1 -> exti1)
  HAL_NVIC_SetPriority(EXTI0_IRQn, ENCODER_INTERRUPT_PRIORITY, 0);
  HAL_NVIC_EnableIRQ(EXTI0_IRQn);
  HAL_NVIC_SetPriority(EXTI1_IRQn, ENCODER_INTERRUPT_PRIORITY, 0);
  HAL_NVIC_EnableIRQ(EXTI1_IRQn);

  // player 1 button pins (input with pull-up, buttons are active-low)
  GPIO_InitStruct.Pin =
      PLAYER1_ENCODER_PUSH_PIN | PLAYER1_MENU_BUTTON_PIN | PLAYER1_BACK_BUTTON_PIN | PLAYER1_TAP_BUTTON_PIN;
  GPIO_InitStruct.Mode = GPIO_MODE_INPUT;
  GPIO_InitStruct.Pull = GPIO_PULLUP;
  GPIO_InitStruct.Speed = GPIO_SPEED_FREQ_LOW;
  HAL_GPIO_Init(PLAYER1_BUTTON_PORT, &GPIO_InitStruct);

  // <---- player 2 gpio configuration ---->

  // player 2 encoder pins (exti on both edges for interrupt-driven quadrature decoding)
  GPIO_InitStruct.Pin = PLAYER2_ENCODER_A_PIN | PLAYER2_ENCODER_B_PIN;
  GPIO_InitStruct.Mode = GPIO_MODE_IT_RISING_FALLING;
  GPIO_InitStruct.Pull = GPIO_PULLUP;
  GPIO_InitStruct.Speed = GPIO_SPEED_FREQ_LOW;
  HAL_GPIO_Init(PLAYER2_ENCODER_PORT, &GPIO_InitStruct);

  // enable exti interrupts for player 2 encoder (pb12 + pb13 -> shared exti15_10)
  HAL_NVIC_SetPriority(EXTI15_10_IRQn, ENCODER_INTERRUPT_PRIORITY, 0);
  HAL_NVIC_EnableIRQ(EXTI15_10_IRQn);

  // player 2 button pins on port b (input with pull-up)
  GPIO_InitStruct.Pin = PLAYER2_ENCODER_PUSH_PIN | PLAYER2_MENU_BUTTON_PIN;
  GPIO_InitStruct.Mode = GPIO_MODE_INPUT;
  GPIO_InitStruct.Pull = GPIO_PULLUP;
  GPIO_InitStruct.Speed = GPIO_SPEED_FREQ_LOW;
  HAL_GPIO_Init(PLAYER2_BUTTON_PORT_B, &GPIO_InitStruct);

  // player 2 button pins on port a (input with pull-up) (not enough pins left on port b)
  GPIO_InitStruct.Pin = PLAYER2_BACK_BUTTON_PIN | PLAYER2_TAP_BUTTON_PIN;
  GPIO_InitStruct.Mode = GPIO_MODE_INPUT;
  GPIO_InitStruct.Pull = GPIO_PULLUP;
  GPIO_InitStruct.Speed = GPIO_SPEED_FREQ_LOW;
  HAL_GPIO_Init(PLAYER2_BUTTON_PORT_A, &GPIO_InitStruct);

  // <---- buzzer gpio configuration ---->

  // buzzer pin configured as alternate function for tim3 pwm
  GPIO_InitStruct.Pin = BUZZER_PIN;
  GPIO_InitStruct.Mode = GPIO_MODE_AF_PP;
  GPIO_InitStruct.Speed = GPIO_SPEED_FREQ_HIGH;
  GPIO_InitStruct.Pull = GPIO_NOPULL;
  HAL_GPIO_Init(BUZZER_PORT, &GPIO_InitStruct);
}

// <---- i2c initialization ---->
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

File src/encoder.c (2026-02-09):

/*
 * rotary encoder module implementation
 * uses quadrature decoding to detect rotation direction
 */

#include "encoder.h"
#include "stm32f1xx_hal.h"

// <---- encoder state tracking ---->

typedef struct {
    GPIO_TypeDef *port;      // gpio port for encoder pins
    uint16_t pin_a;          // encoder channel a pin
    uint16_t pin_b;          // encoder channel b pin
    uint8_t last_state;      // previous state of channels (2 bits: BA)
    volatile int8_t delta;            // accumulated rotation count since last read (volatile: written by isr, read by main)
    int8_t direction_multiplier; // +1 or -1 for direction inversion
} encoder_state_t;

// array of all encoder states
static encoder_state_t encoders[ENCODER_COUNT];

// <---- encoder configuration table ---->

// maps encoder id to gpio port and pins
typedef struct {
    GPIO_TypeDef *port;
    uint16_t pin_a;
    uint16_t pin_b;
    int8_t direction_multiplier;  // +1 or -1 to invert direction if needed
} encoder_config_t;

static const encoder_config_t encoder_configs[ENCODER_COUNT] = {
    {PLAYER1_ENCODER_PORT, PLAYER1_ENCODER_A_PIN, PLAYER1_ENCODER_B_PIN, -1},  // ENCODER_PLAYER1 (inverted)
    {PLAYER2_ENCODER_PORT, PLAYER2_ENCODER_A_PIN, PLAYER2_ENCODER_B_PIN, -1}   // ENCODER_PLAYER2 (inverted)
};

// <---- quadrature decoding lookup table ---->

// quadrature state transition table
// rows: previous state (0-3), columns: current state (0-3)
// values: -1 (ccw), 0 (no change/invalid), +1 (cw)
// state encoding: bit1=B, bit0=A (00, 01, 10, 11)
static const int8_t quadrature_table[4][4] = {
    //  00   01   10   11    <- current state
    {   0,  -1,  +1,   0 },  // 00 <- previous state
    {  +1,   0,   0,  -1 },  // 01
    {  -1,   0,   0,  +1 },  // 10
    {   0,  +1,  -1,   0 }   // 11
};

//click accumulator (4 transitions = 1 physical click)
static int8_t click_fractional[ENCODER_COUNT] = {0, 0};

// <---- initialization ---->

void encoder_init(void) {
    // initialize all encoder states
    for (uint8_t i = 0; i < ENCODER_COUNT; i++) {
        encoders[i].port = encoder_configs[i].port;
        encoders[i].pin_a = encoder_configs[i].pin_a;
        encoders[i].pin_b = encoder_configs[i].pin_b;
        encoders[i].direction_multiplier = encoder_configs[i].direction_multiplier;
        encoders[i].delta = 0;
        click_fractional[i] = 0;
        
        // read initial state of encoder pins
        uint8_t a = (HAL_GPIO_ReadPin(encoders[i].port, encoders[i].pin_a) == GPIO_PIN_SET) ? 1 : 0;
        uint8_t b = (HAL_GPIO_ReadPin(encoders[i].port, encoders[i].pin_b) == GPIO_PIN_SET) ? 1 : 0;
        encoders[i].last_state = (b << 1) | a;  // combine into 2-bit state
    }
}

// <---- internal helper: process encoder state change ---->

// called from isr context to decode quadrature transition for one encoder
static void encoder_process_isr(encoder_id_t encoder_id) {
    encoder_state_t *enc = &encoders[encoder_id];

    // read current state of both encoder pins
    uint8_t a = (HAL_GPIO_ReadPin(enc->port, enc->pin_a) == GPIO_PIN_SET) ? 1 : 0;
    uint8_t b = (HAL_GPIO_ReadPin(enc->port, enc->pin_b) == GPIO_PIN_SET) ? 1 : 0;
    uint8_t current_state = (b << 1) | a;  // combine into 2-bit state (BA)

    // look up rotation direction from quadrature table
    int8_t direction = quadrature_table[enc->last_state][current_state];

    // only accumulate valid transitions (filter out invalid/noise)
    if (direction != 0) {
        enc->delta += (direction * enc->direction_multiplier);
    }

    // update last state
    enc->last_state = current_state;
}

// <---- exti interrupt handlers ---->

// exti0 isr: triggered by pa0 (player 1 encoder channel a)
void EXTI0_IRQHandler(void) {
    // clear the exti pending bit for pin 0
    __HAL_GPIO_EXTI_CLEAR_IT(PLAYER1_ENCODER_A_PIN);

    // process player 1 encoder state change
    encoder_process_isr(ENCODER_PLAYER1);
}

// exti1 isr: triggered by pa1 (player 1 encoder channel b)
void EXTI1_IRQHandler(void) {
    // clear the exti pending bit for pin 1
    __HAL_GPIO_EXTI_CLEAR_IT(PLAYER1_ENCODER_B_PIN);

    // process player 1 encoder state change
    encoder_process_isr(ENCODER_PLAYER1);
}

// exti15_10 isr: triggered by pb12 or pb13 (player 2 encoder channels a and b)
void EXTI15_10_IRQHandler(void) {
    // check which pin triggered and clear it
    if (__HAL_GPIO_EXTI_GET_IT(PLAYER2_ENCODER_A_PIN) != RESET) {
        __HAL_GPIO_EXTI_CLEAR_IT(PLAYER2_ENCODER_A_PIN);
    }
    if (__HAL_GPIO_EXTI_GET_IT(PLAYER2_ENCODER_B_PIN) != RESET) {
        __HAL_GPIO_EXTI_CLEAR_IT(PLAYER2_ENCODER_B_PIN);
    }

    // process player 2 encoder state change (same logic regardless of which pin triggered)
    encoder_process_isr(ENCODER_PLAYER2);
}

// <---- encoder reading ---->

static int8_t encoder_get_delta(encoder_id_t encoder) {
    if (encoder >= ENCODER_COUNT) {
        return 0;
    }

    // disable interrupts briefly to prevent isr from modifying delta
    // between the read and the clear (atomic read-and-clear)
    __disable_irq();
    int8_t delta = encoders[encoder].delta;
    encoders[encoder].delta = 0;
    __enable_irq();

    return delta;
}


int8_t encoder_get_clicks(encoder_id_t encoder) {
    if (encoder >= ENCODER_COUNT) {
        return 0;
    }

    // accumulate raw transitions
    click_fractional[encoder] += encoder_get_delta(encoder);

    // convert to whole clicks
    int8_t clicks = 0;
    while (click_fractional[encoder] >= ENCODER_PULSES_PER_CLICK) {
        clicks++;
        click_fractional[encoder] -= ENCODER_PULSES_PER_CLICK;
    }
    while (click_fractional[encoder] <= -ENCODER_PULSES_PER_CLICK) {
        clicks--;
        click_fractional[encoder] += ENCODER_PULSES_PER_CLICK;
    }
    return clicks;
}

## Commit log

2026-02-05 fix encoder double counting in test
    [main.c]
2026-02-05 fix player 1 tap button pin conflict
    [main.c]
2026-02-05 add proper piezo buzzer suppor. pending: make it louder
    [main.c]
2026-02-08 implement button management( button.h+button.c)
2026-02-08 implement encoder management( encoder.h + encoder.c)
2026-02-09 fix screen flickering across the board by implementing smart redraws
    [main.c, menu.c]
2026-02-09 fix current bonus time editing bug. fix header ficklering
    [display.c, game.c, main.c]
2026-02-11 implement power on splash screen
2026-02-13 fix stale back button press in main menu, change splash screen
    [menu.c]
2026-02-13 invert power un splash art to dark mode
2026-02-13 fix 'Ready' screen in armed state not showing correct time after editing it
    [game.c]
2026-02-17 add buzzer on/off toggle to both main menus
    [game.c, main.c, menu.c]
2026-02-24 fix stale button presses across state transitions
    [game.c, menu.c]
2026-02-24 increase buzzer beep duration
    [game.c]
2026-02-26 add 3D print files and Blender sources for casing and gift box
    [chess clock display holder.blend, chess clock display holder.stl, chessclock BASE.stl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]
